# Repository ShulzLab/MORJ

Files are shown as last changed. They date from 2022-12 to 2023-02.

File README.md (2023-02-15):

## What does MORJ means anyway ?     

**MORJ** stands for **M**otorized **O**ptical **R**otary **J**oint, and is a device used for wide field fibroscopic imaging in freely moving animals.

It refers to a technical solution developed to enhance the use of dense multifibre beams for recording optical fluorescence signals in the brain of small, freely-moving animals. 

<div style="clear: both;">
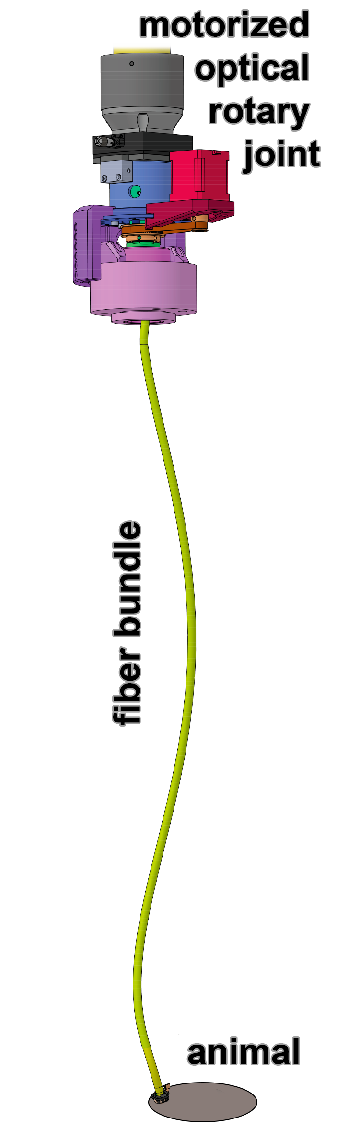
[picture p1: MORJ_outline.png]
MORJ
  
</div><h2> What is the rationale behind the development of this device ?</h2>

The use of rotating optical joints to allow light to pass through a fixed optical arrangement to one or a few rotating waveguides is quite common. However, there are few or no solutions for the use of dense multifibre waveguides. This usually leads neuroscientists wishing to study ethologically relevant behaviours in freely moving animals to use long sets of relatively rigid fibre bundles and to sporadically interrupt experiments to untangle the twist in the fibre as the animal moves and rotates, which in turn leads to disruption of the animal's behaviour.

The solution we have developed and described in this repository and in the peer-reviewed publication (*link Neurophotonics*) has allowed us to remove this limitation. By allowing rotation of the fibre bundle while being able to record stable sequences intermittently, it is possible to take full advantage of the use of fiberscopes to study natural behavioural repertoires.

## How does it works ?

In short, it uses an optical rotary joint similar to that described above, but adds motorised rotative control of angular position. This control is tuned to the orientation of the animal by directly reading its movements using an inertial measurement unit, and to the outputs of external devices so that it can be easily included in an experimental setup.

The rotation of the fiber bundle at the joint constantly follows the rotation of the animal while the controller is in "standby mode".

When fluorescence recording is desired, an electronic digital logic signal is used to trigger the controller into "recording mode". It instantly stops setting the rotation according to the animal's orientation and rather takes the shortest route to a precise and stable reference orientation. (OREF) It remains there while the recording is in progress. Once the recording is finished and the digital trigger signal goes low, the "standy mode" is used again.

More details on the operation of the device are available in the [`doc`](./doc) folder.

## What if I need to record over long periods of time without interruption ?

For the context in which we developed this device, we needed to make recordings of 1 second, approximately every 6 seconds depending on the animal's behaviour.

There are several solutions that can easily be implemented to make long recordings.

- In the case **short interruptions are acceptable**,  the simplest solution is to modify the behaviour of the joint controller so that the joint defaults to "record mode" and can control the start and stop of the acquisition device to which it is connected. When the torsion (the amount of rotation of the animal relative to the fixed position of the current 'record mode') exceeds a user-defined value, the 'record mode' is briefly stopped and so is the acquisition. The joint is rapidly rotated to the nearest reference orientation (OREF) where torsion is minimal. Once this movement is complete (full turns are completed in less than half a second with our device), the joint returns to the stable "recording mode" and commands the start of a new image sequence from the acquisition device. This process can continue indefinitely, resulting in image sequences of varying length depending on the rate of rotation of the animal.
- In the case **uninterrupted constant sampling rate signal is required**, a more complex solution is to rely of the fact that the motor position is known at all times. Thus, an alternate "constant recording mode" can be set, where the joint can move between periods of exposure of an image by the acquisition device.

At present, the first method has been implemented in the joint controller, but has not been tested in any significant experiments. The second method has not yet been implemented in the joint controller code, but will be developed in the future. 

## How can I build a device based on the same principle ?

- Build instructions are available here.

- 3D models documents and electronic parts and circuits are available in the [`electromechanical`](./electromechanical) folder.

- Code for the control and user interface are available in the [`software`](./software) folder.

## Why deciding to pattent this ?

The purpose of publishing and depositing this device was to make it available to other neuroscience researchers and to promote the study of ethologically relevant behaviours.

The publication and this current repository document the benefits, limitations, and future improvements associated with the device, and make this information available for others to use and replicate. However, adapting this device for your own laboratory will always represent a cost, including drawings and code, using or converting parts for your own particular optical system or fiber. Making or choosing your own electronics to control and interface with other parts of your installation can also be a substantial time investment. Although we have tried to make most of the information available to you so as not to go down the whole path of research and development that we did, you will still need a decent amount of man hours to build one and make it work reliably. Such time ressources in public research tend to be somewhat precious (scarce) ones, and the fact that an industrial company could take care of this for you in a more efficient and versatile way is also a great advantage for many labs. This is why we decided to patent this new design as it grants possible access to special funding from universities and technology transfer offices that may help cover the expenses of this knowledge transfer and associated product development for the industrial company.

If you are an industrial actor and would be interested in proposing to neurophysiological researchers a commercial product using the technology described in the [registered pattent](https://data.inpi.fr/brevets/FR3121999), you can contact us at isabelle.ferezou @t cnrs.fr or daniel.shulz @t cnrs.fr or timothe.jost-mousseau @t pasteur.fr

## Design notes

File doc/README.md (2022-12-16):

## Motorized Optical Rotary Joint :

#### - [Build Instructions](./build_instructions.md) 

#### - [Detailed explanation of elements and operating modes](./detailed_operations.md)

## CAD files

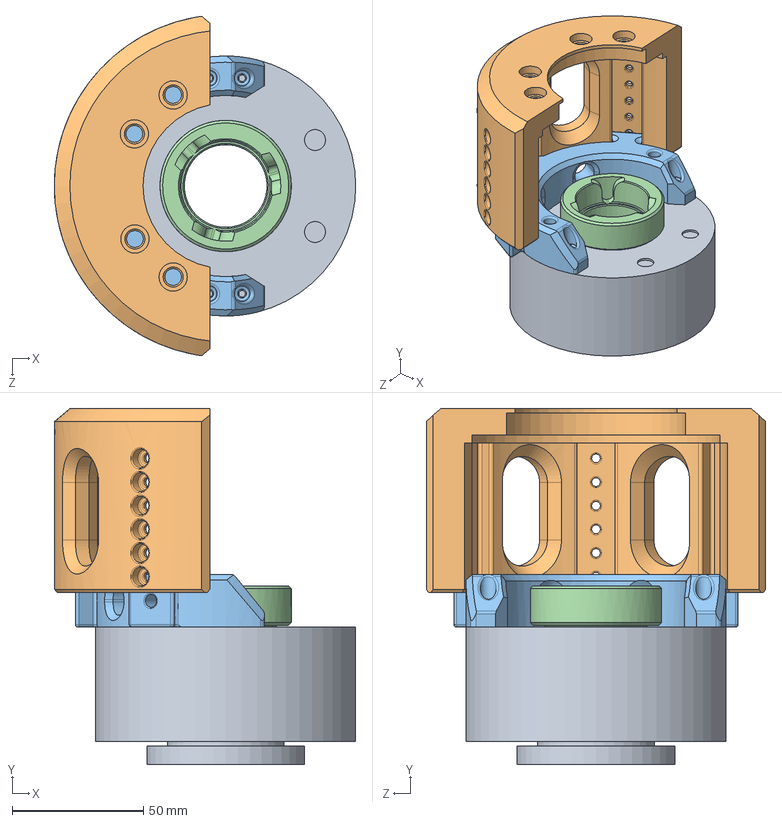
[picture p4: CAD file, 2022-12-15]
electromechanical/3D_files/electrical_rotary_joint/electrical_rotary_joint.SLDASM
114.7 x 135.5 x 129.2 mm
electrical_slip_ring_Jinpat_ LPT038-6
dovetail_fixed_body
dovetail_mobile_body
driving_ring

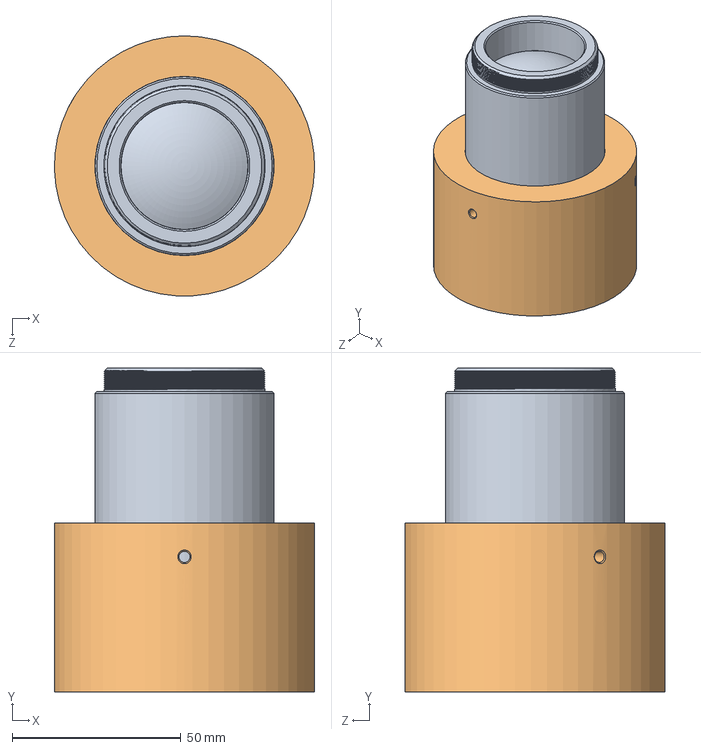
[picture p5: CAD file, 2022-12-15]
electromechanical/3D_files/upstream_optical_assembly/upstream_optical_assembly.SLDASM
77.1 x 96.0 x 77.1 mm
Lens
Lens_hood

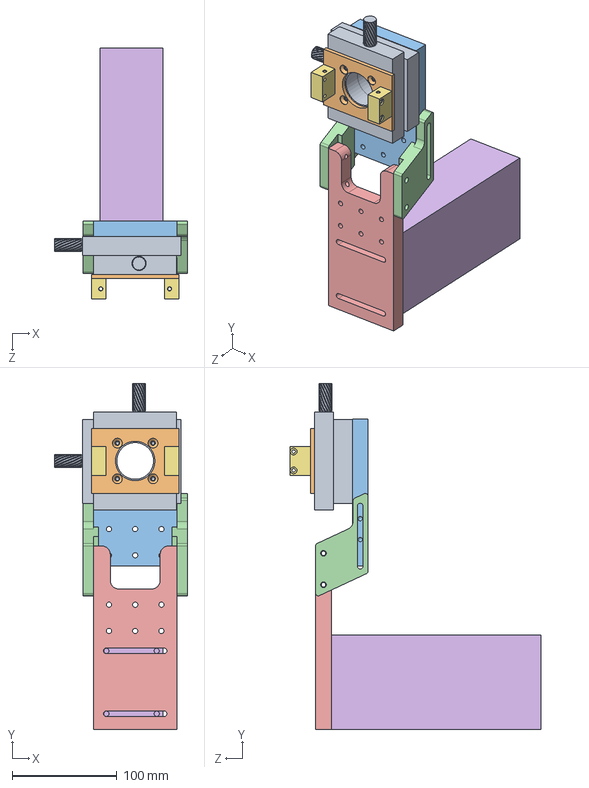
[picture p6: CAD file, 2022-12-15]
electromechanical/3D_files/xyz_adjustment_system/xyz_adjustment_system.SLDASM
127.1 x 330.0 x 239.5 mm
Platine_Ajustement
PlaqueInterne_LENS
Top_focus_holder
right_lateral_focus_holder x 2
Bottom_focus_holder
focus_adjuster_proxy
BlocAdaptation x 2

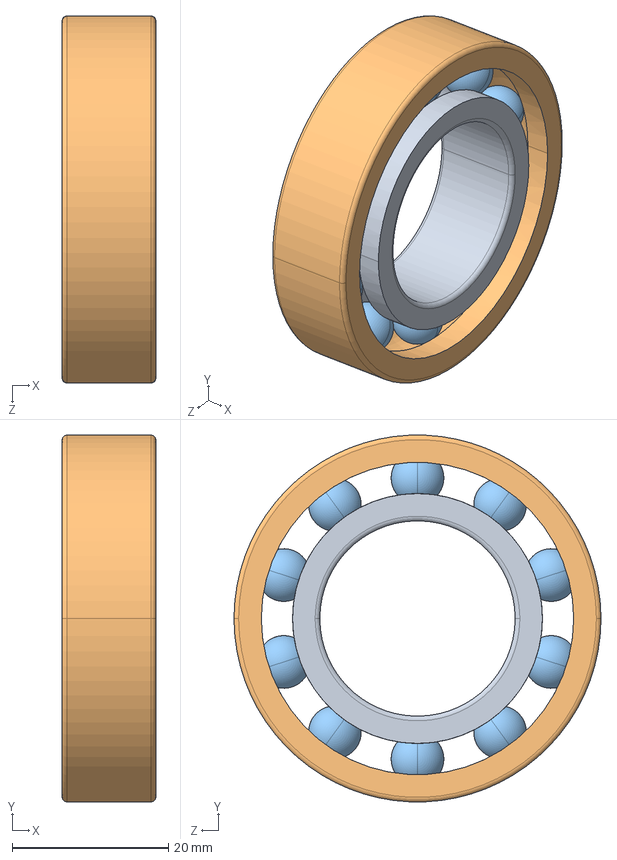
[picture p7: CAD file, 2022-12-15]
electromechanical/3D_files/optical_rotary_joint/roller_bearing/RollerBearing_6005_HC5C3.SLDASM
12.0 x 47.0 x 47.0 mm
inner_grove
outer_grove
roller_ball x 10

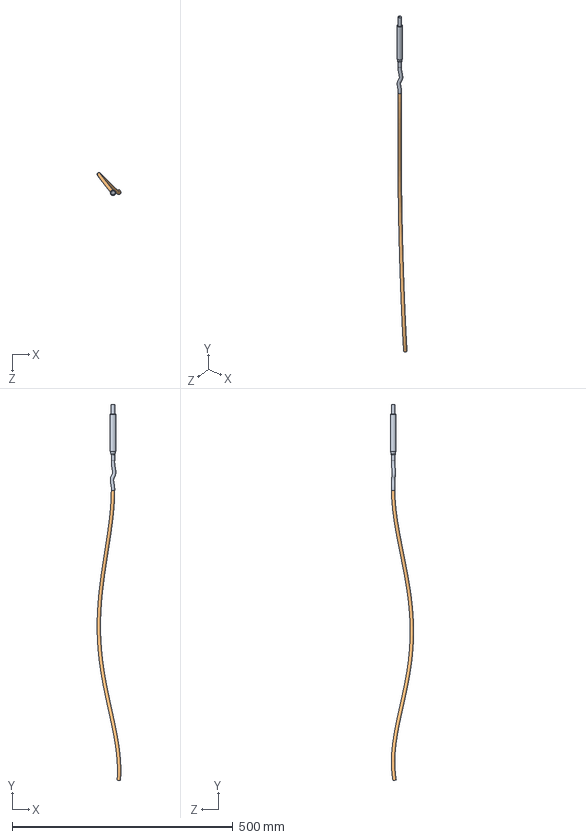
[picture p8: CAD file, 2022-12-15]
electromechanical/3D_files/downstream_optical_assembly/downstream_optical_assembly.SLDASM
53.9 x 851.9 x 52.6 mm
Fiber_proximal_end
Fiber_body

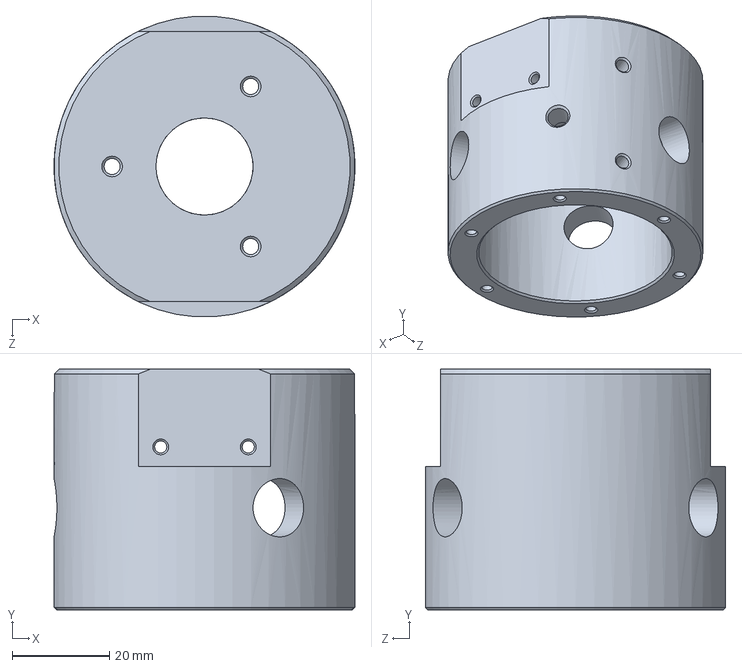
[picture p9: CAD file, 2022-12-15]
electromechanical/3D_files/optical_rotary_joint/main_static_body.SLDPRT
61.9 x 49.5 x 61.8 mm

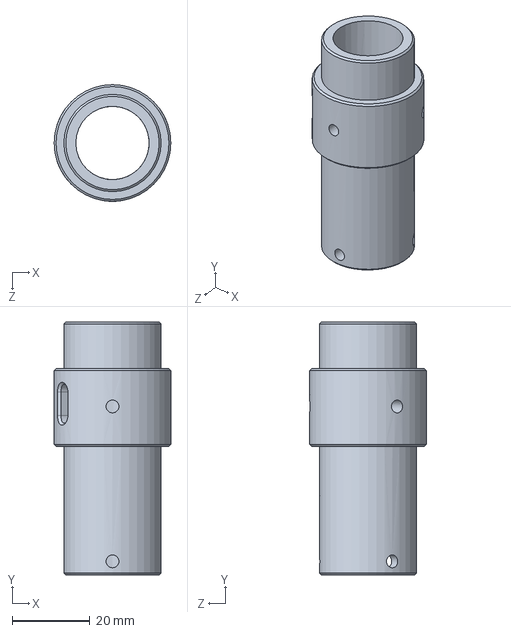
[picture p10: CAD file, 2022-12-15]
electromechanical/3D_files/optical_rotary_joint/main_rotative_body.SLDPRT
30.0 x 65.0 x 30.0 mm

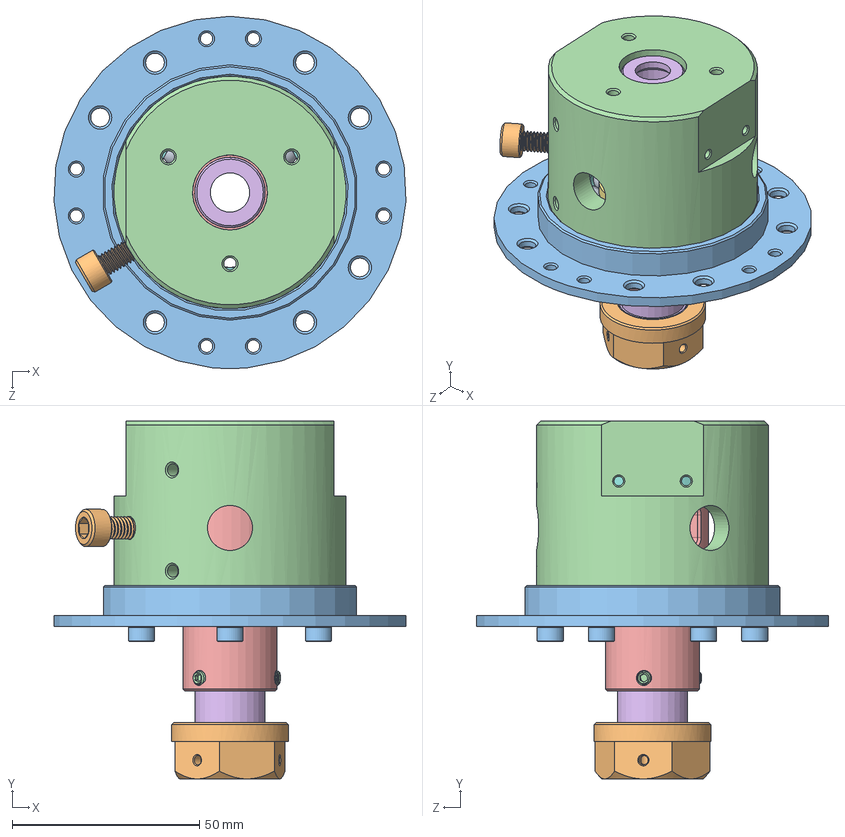
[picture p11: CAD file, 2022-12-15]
electromechanical/3D_files/optical_rotary_joint/optical_rotary_joint.SLDASM
93.9 x 95.4 x 94.0 mm
spacer
tightening_nut
endplate
main_static_body
main_rotative_body
adjustable_height_rotative_body
inner_grove x 2
outer_grove x 2
roller_ball x 20
lock_tightening_pin
BTR_M6 x 6
setscrew_M4 x 6

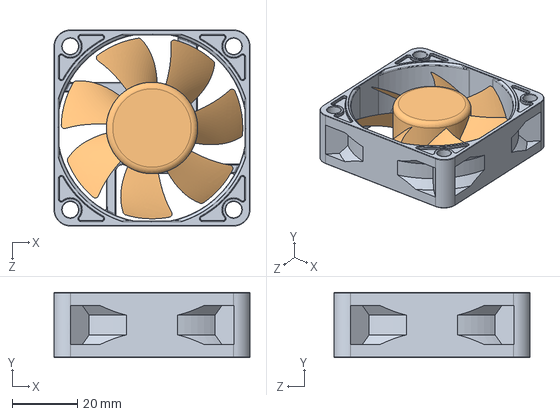
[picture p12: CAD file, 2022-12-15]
electromechanical/3D_files/motor_controller/60mm_fan.SLDASM
60.0 x 20.0 x 60.0 mm
Fan_Case
Fan

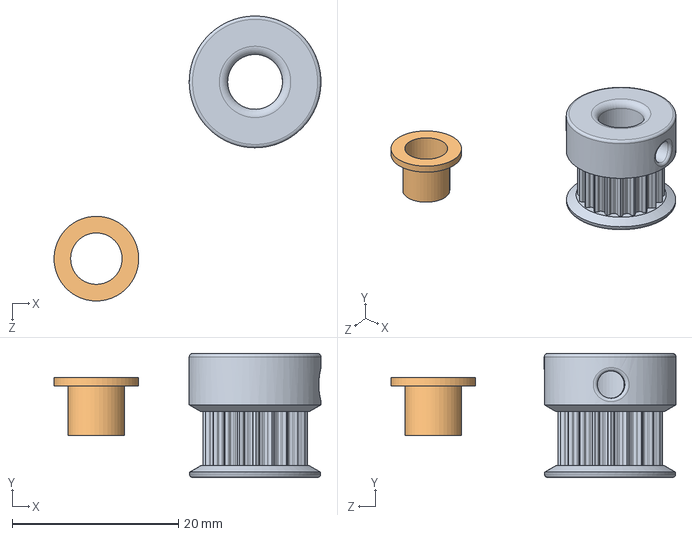
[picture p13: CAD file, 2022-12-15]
electromechanical/3D_files/motor_system/motor_system.SLDASM
32.1 x 14.9 x 34.3 mm
Pulley_GT2_20T
Plot_Roulementplastique

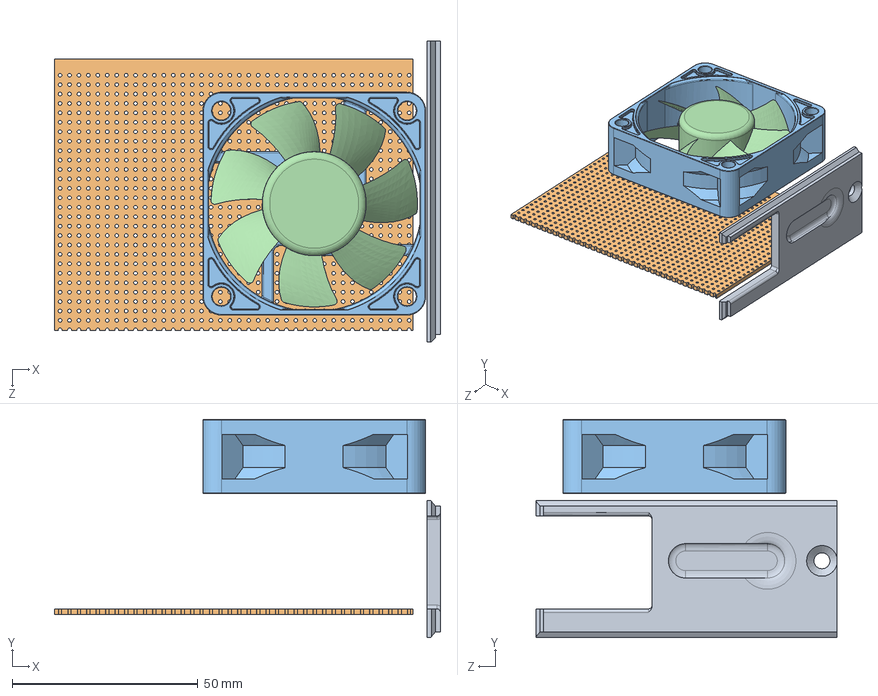
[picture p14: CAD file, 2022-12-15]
electromechanical/3D_files/motor_controller/motor_controller.SLDASM
103.9 x 58.7 x 80.9 mm
proto_board
Fan_Case
Fan
driver_opening_plate

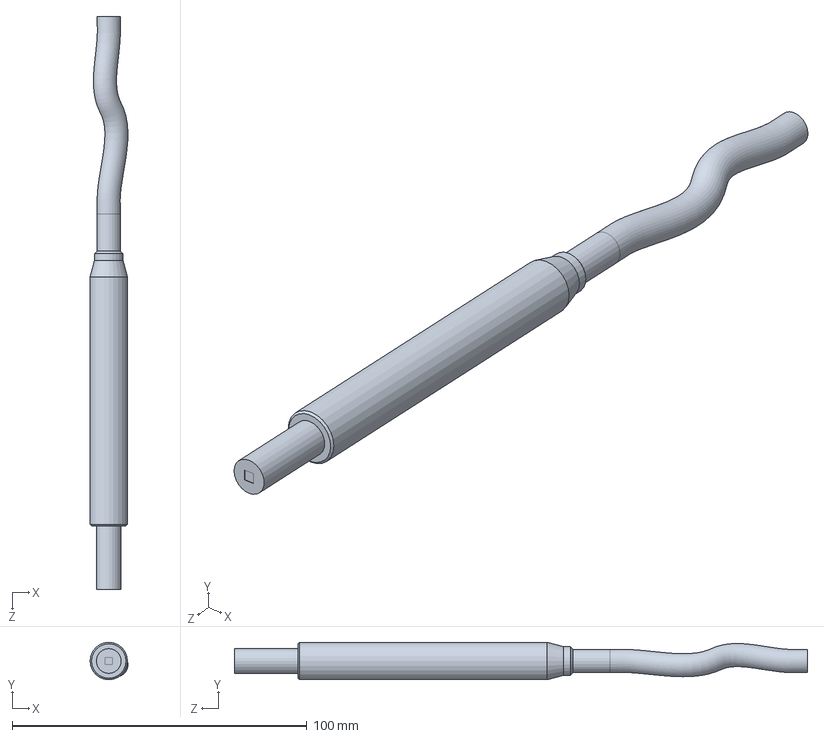
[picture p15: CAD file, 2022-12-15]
electromechanical/3D_files/downstream_optical_assembly/Fiber_proximal_end.SLDPRT
12.9 x 12.7 x 194.3 mm

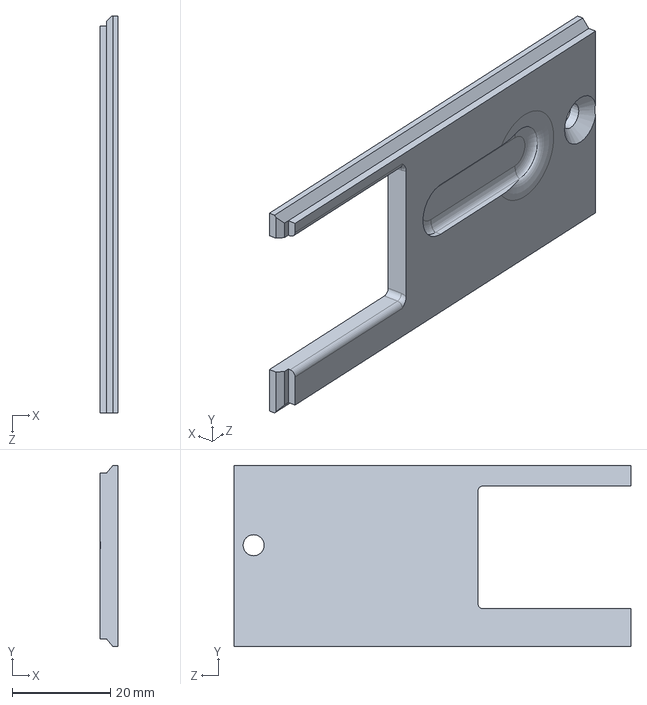
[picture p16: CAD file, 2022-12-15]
electromechanical/3D_files/motor_controller/driver_opening_plate.SLDPRT
3.70 x 36.9 x 80.9 mm

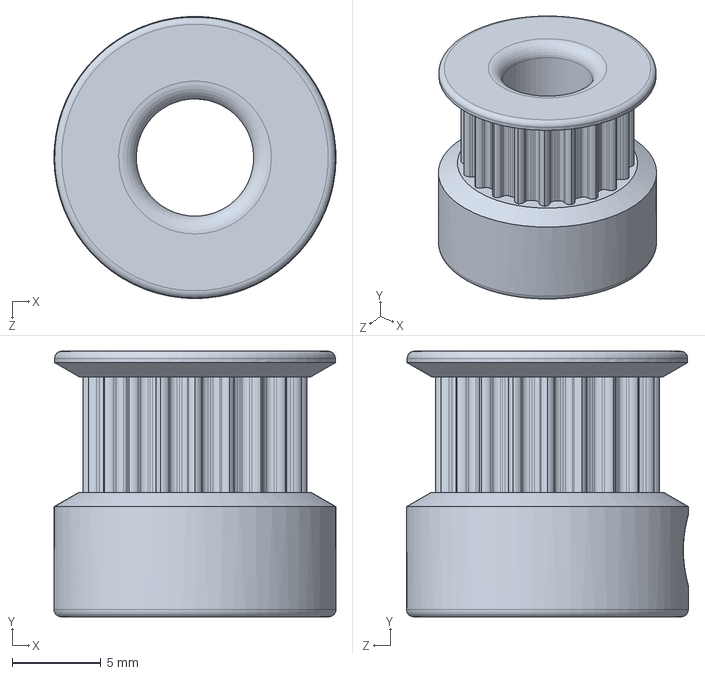
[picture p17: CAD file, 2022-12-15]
electromechanical/3D_files/motor_system/Pulley_GT2_20T.SLDPRT
15.9 x 14.9 x 15.9 mm

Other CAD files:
electromechanical/3D_files/optical_rotary_joint/roller_bearing/outer_grove.SLDPRT
electromechanical/3D_files/downstream_optical_assembly/Fiber_body.SLDPRT
electromechanical/3D_files/electrical_rotary_joint/dovetail_fixed_body.SLDPRT
electromechanical/3D_files/motor_controller/proto_board.SLDPRT
electromechanical/3D_files/electrical_rotary_joint/dovetail_mobile_body.SLDPRT
electromechanical/3D_files/electrical_rotary_joint/driving_ring.SLDPRT
electromechanical/3D_files/electrical_rotary_joint/electrical_slip_ring_Jinpat_ LPT038-6.SLDPRT
electromechanical/3D_files/motor_controller/Fan.SLDPRT
electromechanical/3D_files/motor_controller/Fan_Case.SLDPRT
electromechanical/3D_files/motor_controller/USB_port.SLDPRT
electromechanical/3D_files/motor_controller/attachment_plate.SLDPRT
electromechanical/3D_files/motor_controller/connectors_opening_plate.SLDPRT
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

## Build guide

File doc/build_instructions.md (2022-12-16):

## Build Instructions :

There instructions are to reproduce the device with the files provided in this repository. However, it will be highly likely that you will need to make changes to the design to adapt for your particular situation (optical measurement setup available, dimenstions of the fiber bundle available)

### 1 - The fiber bundle :

The fiber bundle we used is designed by Schott, and is a large diameter (6.25 mm²) [wound image bundle](https://www.schott.com/en-ro/products/flexible-imaging-bundles-p1000343/product-variants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).

<div class="column">
  <div class="row">
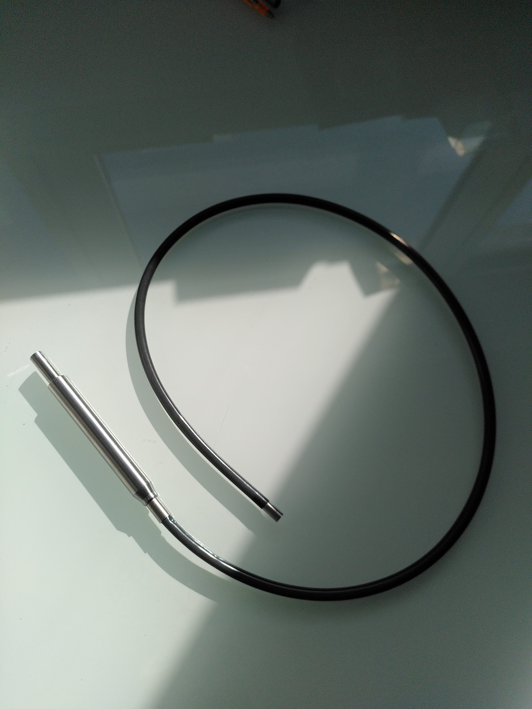
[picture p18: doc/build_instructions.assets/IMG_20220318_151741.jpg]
    
  </div>
  <div class="row">
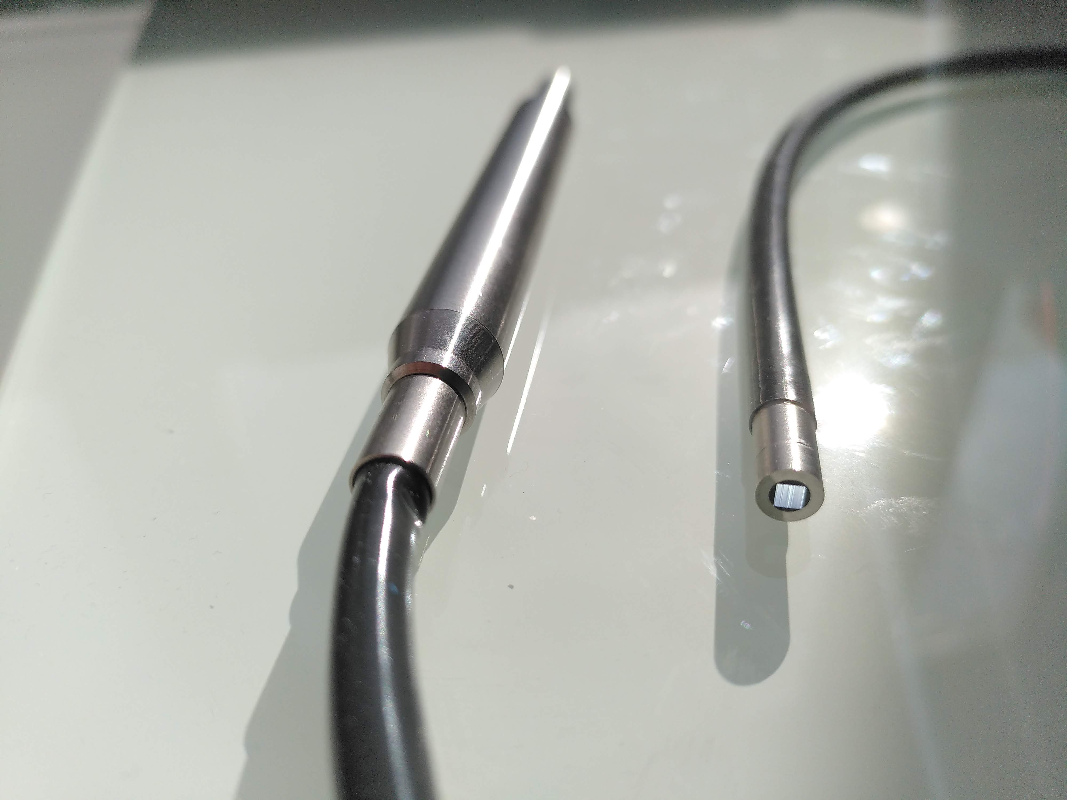
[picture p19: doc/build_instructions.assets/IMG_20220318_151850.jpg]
    
  </div>
</div> 

### 2 - Adapting dimensions to the fiber and objective
<div class="column">
  <div class="row">
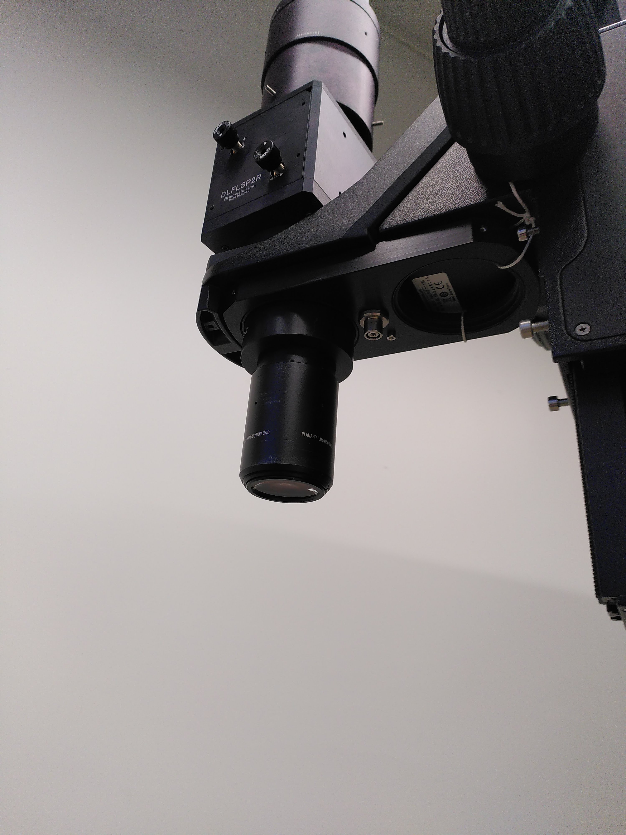
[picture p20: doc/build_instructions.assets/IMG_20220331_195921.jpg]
    
  </div>
  <div class="row">
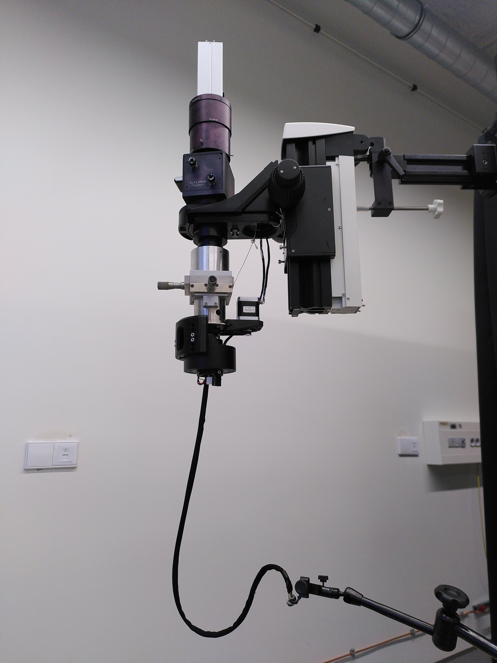
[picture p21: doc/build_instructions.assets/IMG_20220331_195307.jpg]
    
  </div>
</div>

#### From simple "fiber below lens" static mount

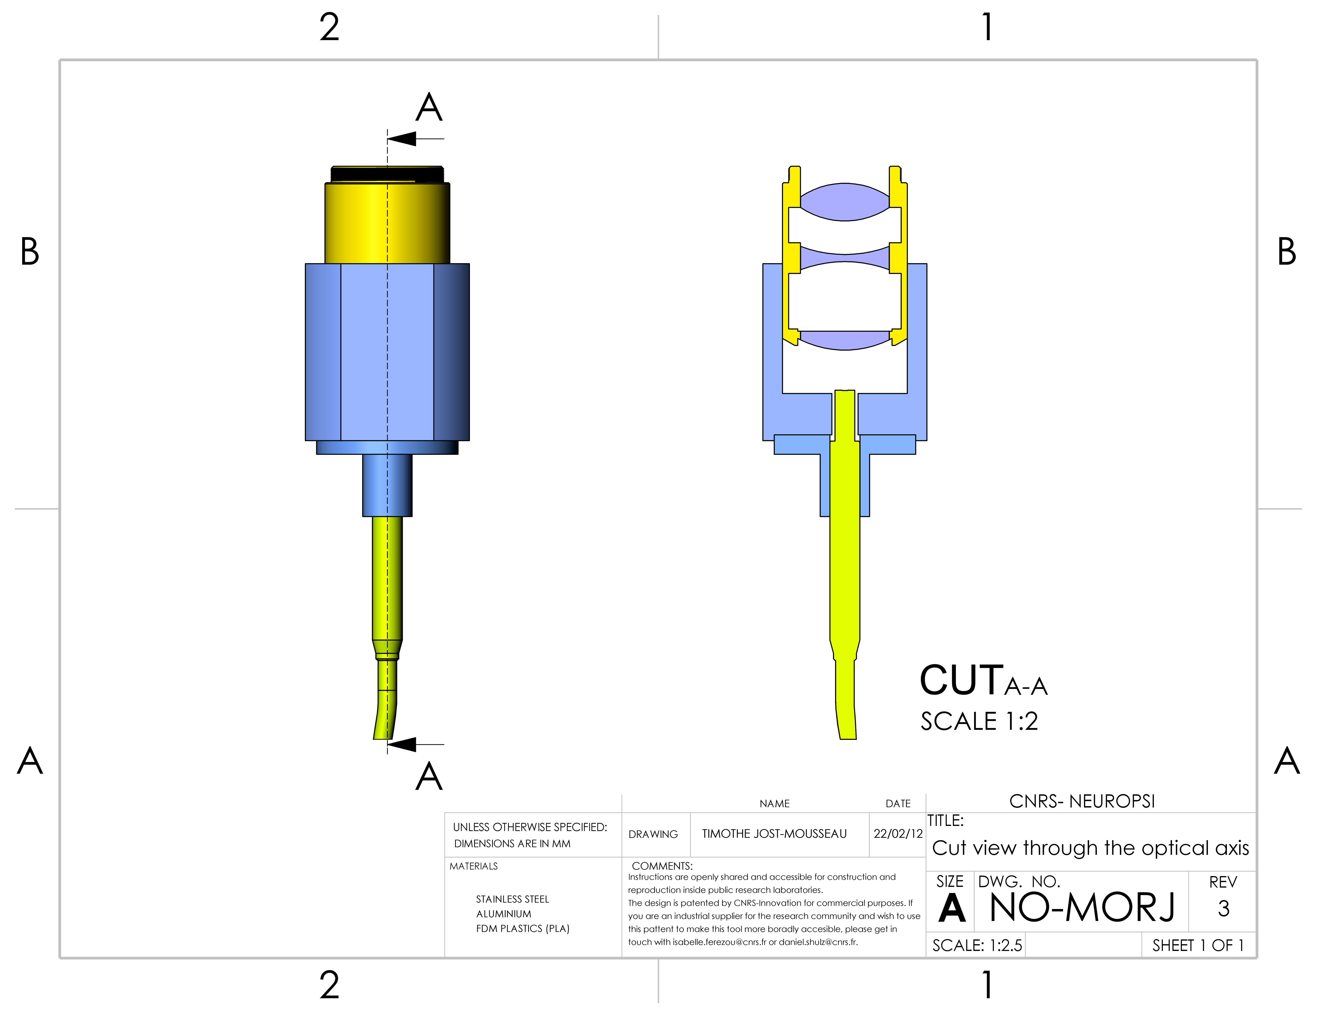
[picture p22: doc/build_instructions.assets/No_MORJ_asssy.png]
No_MORJ_asssy


#### To rotative joint with adapted dimensions for fiber, motor, bearings & electrical joint

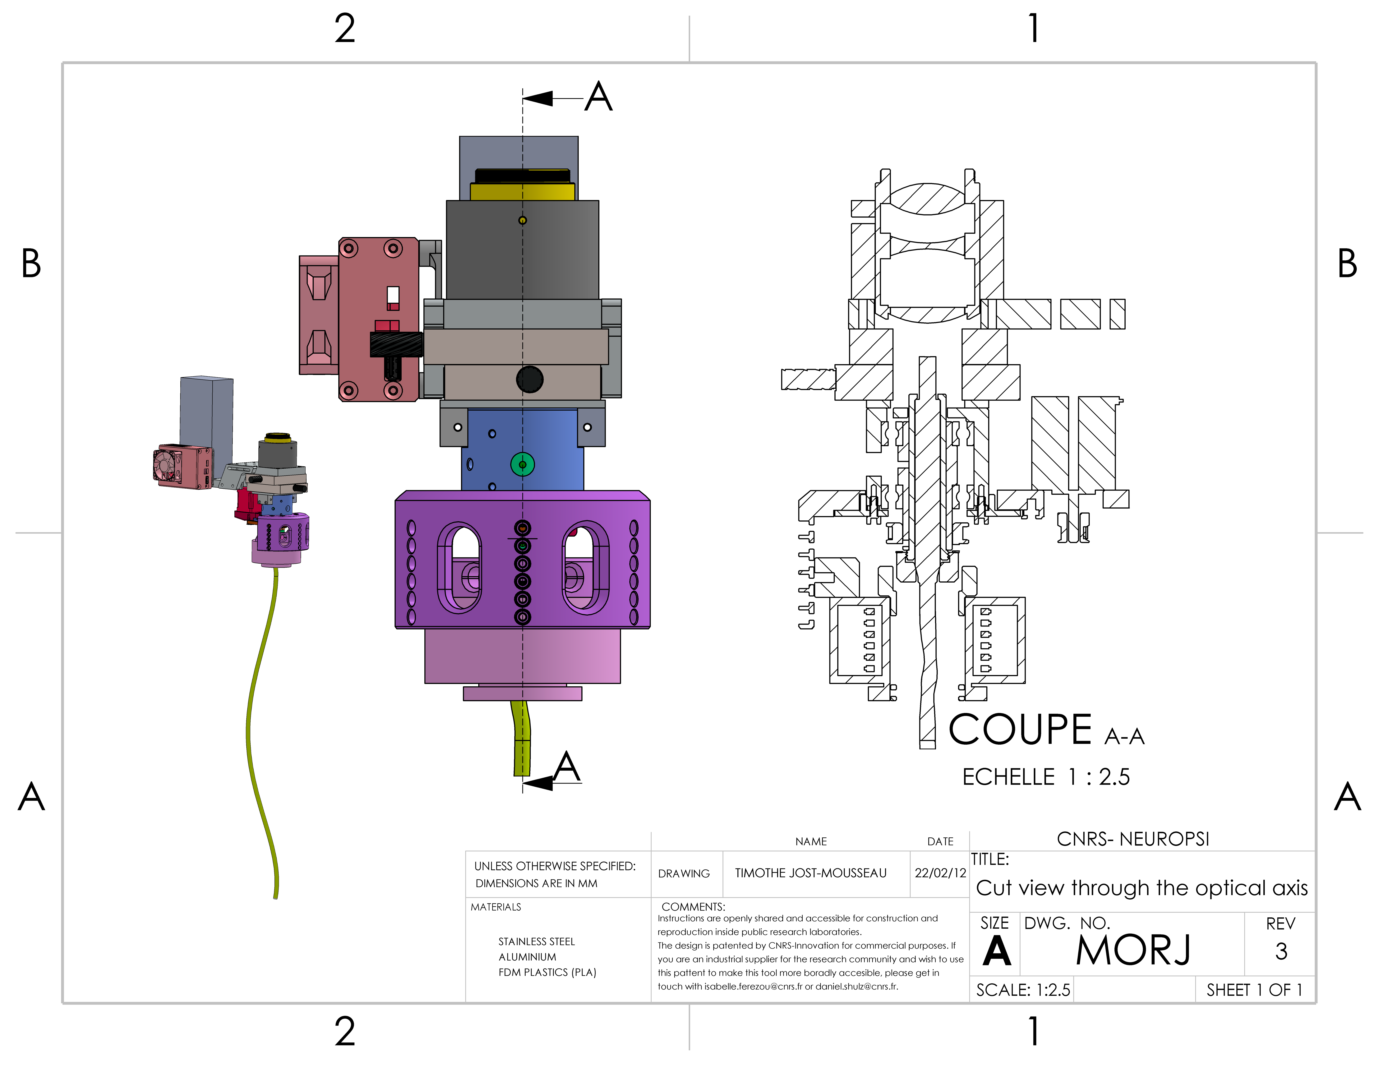
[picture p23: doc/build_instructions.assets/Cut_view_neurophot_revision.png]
Cut_view_neurophot_revision


Planning ahead for a system to adjust focus (Z) and lateral shift (X, Y) with a 2d translation platform is quite handy and important.

### 3 - The inertial measurement unit board

<div class="column">
  <div class="row">
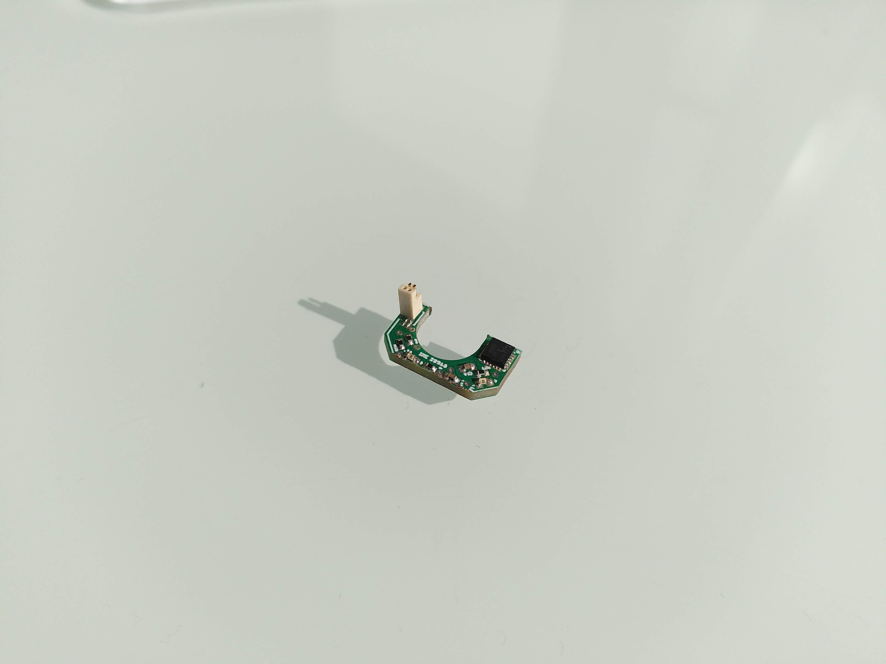
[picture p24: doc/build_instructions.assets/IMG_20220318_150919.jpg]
    
  </div>
  <div class="row">
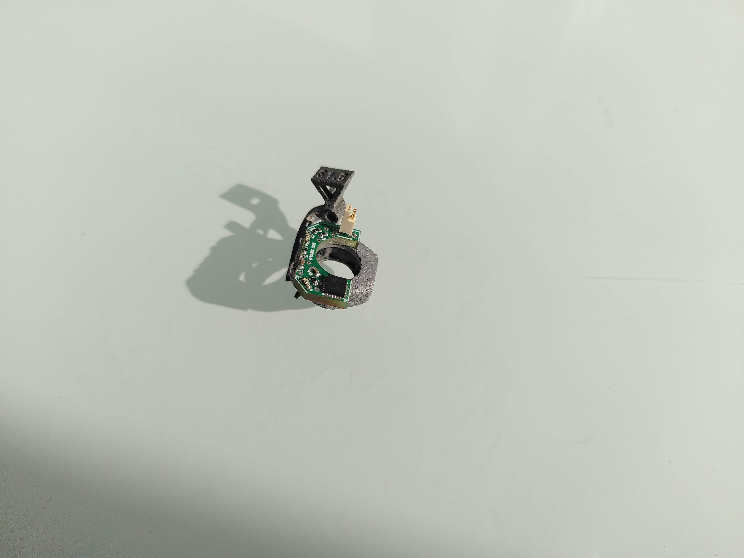
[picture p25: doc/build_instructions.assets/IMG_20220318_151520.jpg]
    
  </div>
</div>

### 4 - Electronic control

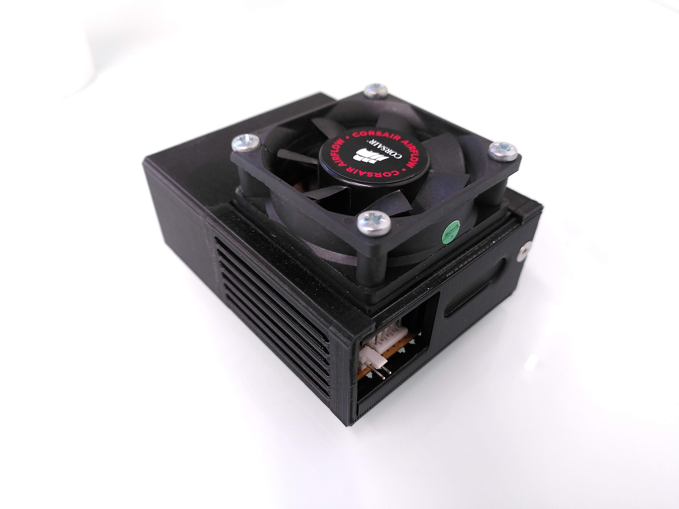
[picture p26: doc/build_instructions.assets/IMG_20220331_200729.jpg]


## 5 - User interface

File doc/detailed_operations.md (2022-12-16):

## All modes of operations :

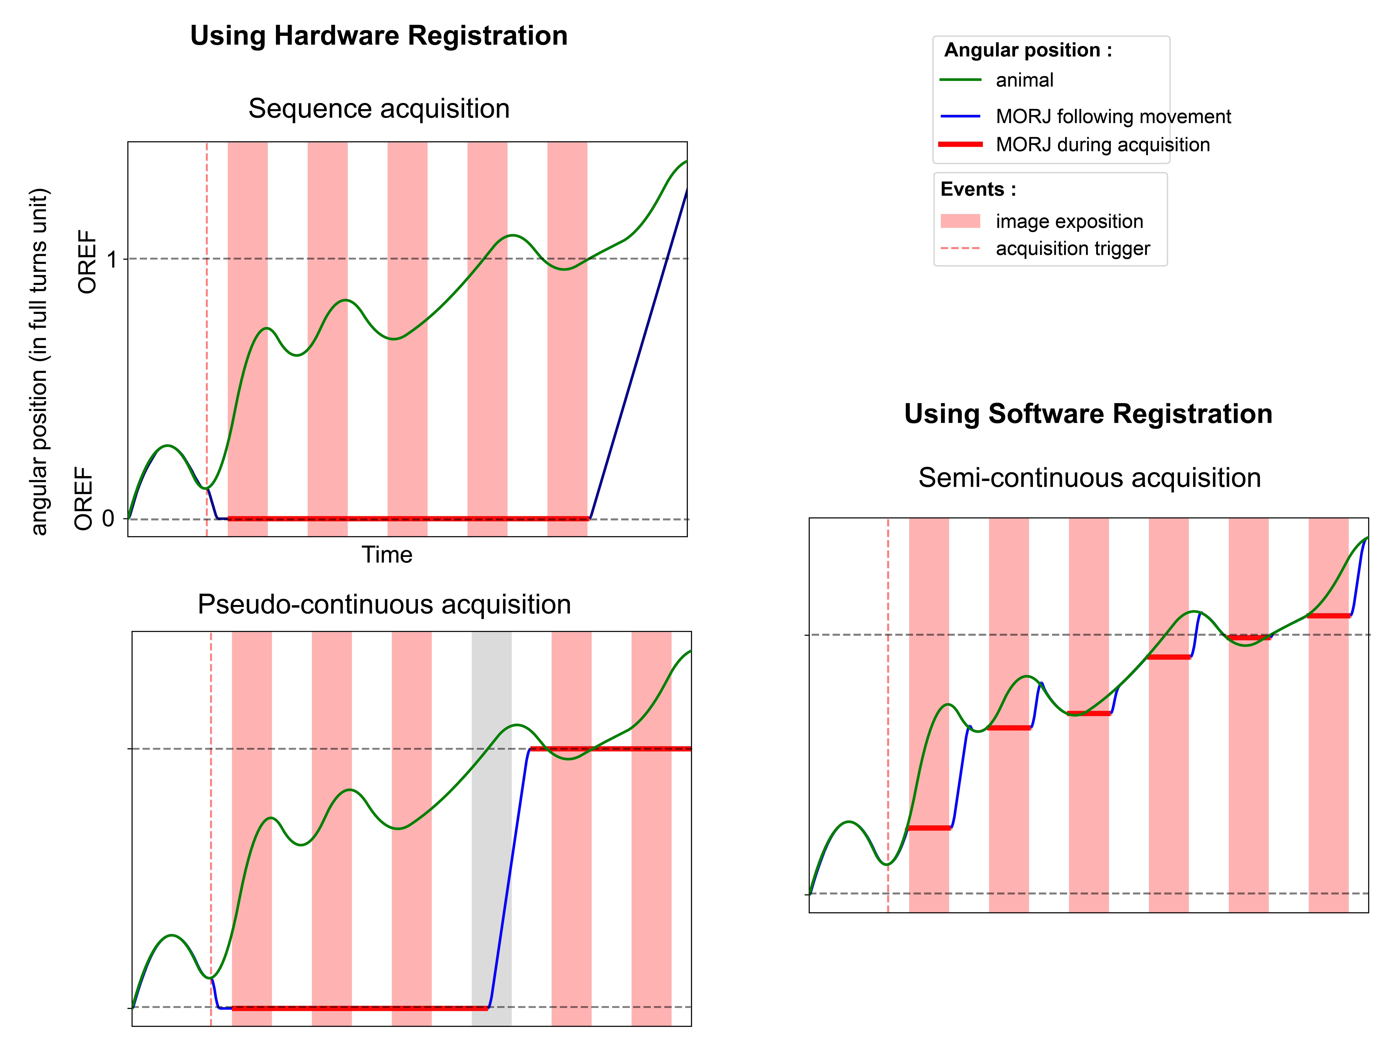
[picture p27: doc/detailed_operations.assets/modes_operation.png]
modes_operation


### Automation process :

[Controller flowchart](detailed_operations.assets/MORJ_controller.pdf)

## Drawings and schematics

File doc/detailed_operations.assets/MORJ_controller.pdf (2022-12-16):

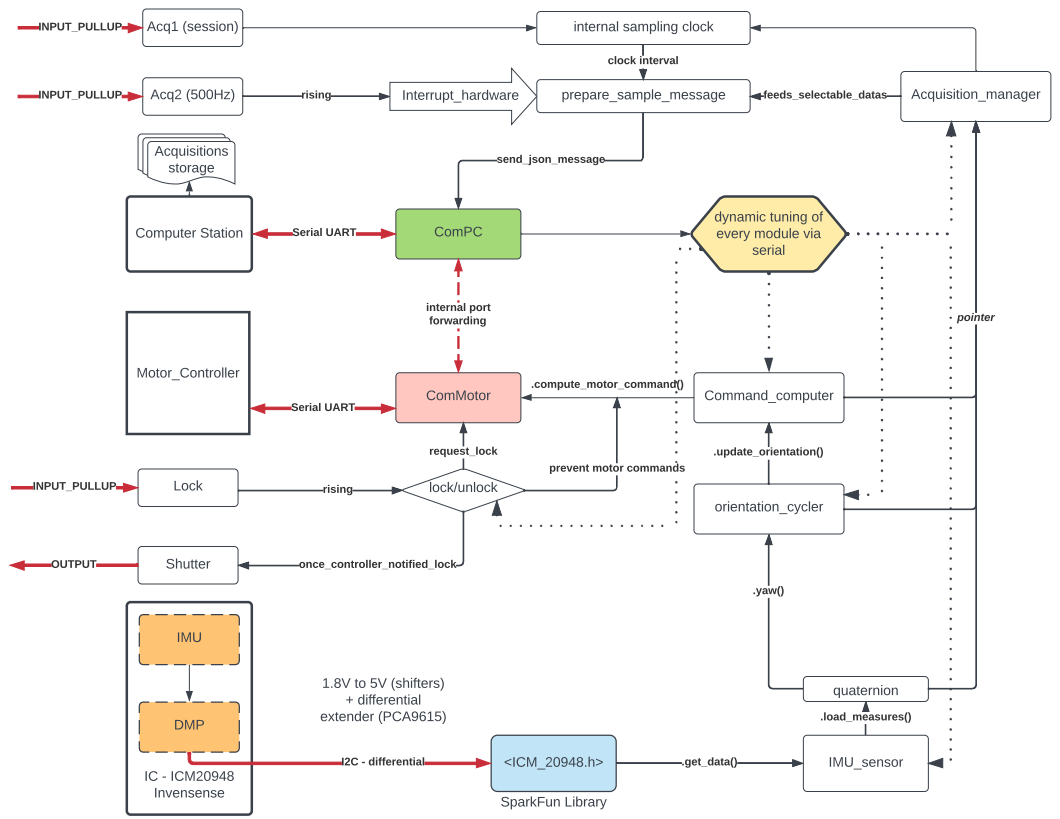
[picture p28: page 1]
IMU; DMP; <ICM_20948.h>; SparkFun Library; I2C - differential; IC - ICM20948 Invensense; 1.8V to 5V (shifters) + differential extender (PCA9615); .get_data(); IMU_sensor; .load_measures(); quaternion; pointer; Acquisition_manager; .yaw(); orientation_cycler; .update_orientation(); ComMotor; Command_computer; .compute_motor_command(); Motor_Controller; Serial UART; Computer Station; ComPC; internal port forwarding; Lock; Shutter; Acq1 (session); INPUT_PULLUP; OUTPUT; Acq2 (500Hz)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

internal sampling clock

dynamic tuning of
every module via
serial

prevent motor commands

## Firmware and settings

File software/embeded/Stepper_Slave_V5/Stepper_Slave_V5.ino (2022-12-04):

#include <stdint.h>

#define PROTOCOL_NO_WAIT_JSON_AKNOWLEDGE 1
#define ARDUINOJSON_DECODE_UNICODE 1
#define PROTOCOL_ITEM_NUMBER 6
#define PROTOCOL_DEBUG_MODE 0


#include "ArduPPPJS.h"
//#include <avr/wdt.h>

#include "DriverClass.h"

#define INTERNAL_TMC_UART Serial5  // UART serial port used to communicate with TMC driver
#define EXTERNAL_DATA_UART Serial4
#define EXTERNAL_COMPUTER_UART Serial

#define INITIALIZATION_WAIT_PERIOD 6000

const int Pin_GreenLED = 12;
const int Pin_RedLED = 11;

constexpr auto glb_Pin_MotorEnable = 7;
constexpr auto glb_Pin_MS1 = 5;
constexpr auto glb_Pin_MS2 = 6;

constexpr auto glb_Pin_Step = 3;
constexpr auto glb_Pin_Dir = 2;

constexpr auto DRIVER_ADDRESS = 0b00;

constexpr float R_SENSE = 0.11;
//#define R_SENSE 0.11f // Match to your driver

int RDOfreq = 100;
bool RDOflag = false;

IntervalTimer RDO_timer;

MORJStepperDriver StepMotor(INTERNAL_TMC_UART, R_SENSE, DRIVER_ADDRESS, glb_Pin_Step, glb_Pin_Dir, glb_Pin_MS1, glb_Pin_MS2);

BJ_ProtocolHandler<PROTOCOL_ITEM_NUMBER> IOs;



#define com_type int32_t
#define com_id 10
#define mpos_type int32_t
#define mpos_id 20
#define abscom_type int32_t
#define abscom_id 30
//#define virtual_type float
//#define virtual_id 230
//#define virtual_type_2 uint64_t
//#define virtual_id_2 158

void PayloadSetup() {
	IOs.append<com_type>(com_id, "command");
	IOs.append<mpos_type>(mpos_id, "motor_pos");
	IOs.append<abscom_type>(abscom_id, "abs_motor_command");
	//IOs.append<virtual_type>(virtual_id, "virtual_float");
	//IOs.append<virtual_type_2>(virtual_id_2, "virtual_uint64");
}

void setup() {
	PayloadSetup();

	pinMode(LED_BUILTIN, OUTPUT);
	pinMode(Pin_GreenLED, OUTPUT);
	pinMode(Pin_RedLED, OUTPUT);
	digitalWrite(LED_BUILTIN, LOW);

	static bool COMPUTER_CONNECTED = false;
	EXTERNAL_COMPUTER_UART.begin(250000);
	while (millis() < INITIALIZATION_WAIT_PERIOD) {
		Wait_and_BlinkLEDs();
		if (EXTERNAL_COMPUTER_UART) {
			COMPUTER_CONNECTED = true;
			break;
		}
	}

	// put your setup code here, to run once:
	INTERNAL_TMC_UART.begin(115200);

	if (COMPUTER_CONNECTED) {
		IOs.begin(EXTERNAL_COMPUTER_UART, EXTERNAL_COMPUTER_UART);
		StepMotor.begin(3, 400, 8, glb_Pin_MotorEnable, EXTERNAL_COMPUTER_UART);
		StepMotor.connectLED(Pin_RedLED);
		StepMotor.SetLedMode(true);
		digitalWrite(Pin_GreenLED, LOW);
		EXTERNAL_COMPUTER_UART.println("{started_in_mode:'computer_usb'}");
	}
	else {
		EXTERNAL_DATA_UART.begin(115200);
		delay(250);
		IOs.begin(EXTERNAL_DATA_UART, EXTERNAL_COMPUTER_UART);
		StepMotor.begin(3, 400, 8, glb_Pin_MotorEnable, EXTERNAL_DATA_UART);
		StepMotor.connectLED(Pin_GreenLED);
		StepMotor.SetLedMode(false);
		digitalWrite(Pin_RedLED, LOW);
		EXTERNAL_COMPUTER_UART.println("{started_in_mode:'external_device'}");
	}

	RDO_timer.priority(129);
	RDO_timer.begin(RDO_IRQ, (long)(1000000 / RDOfreq));

	//StepMotor.toff(5);

	StepMotor.SetMotorCurrent(1600);

	StepMotor.AccelStepper::setMaxSpeed(10000);
	StepMotor.SetMotorAcceleration(20000);
	EXTERNAL_COMPUTER_UART.println("{setup_init:'finished'}");
};

void loop() {
	MessageHandlers();

	bool _temp_lock = StepMotor.EvaluateMovement();
  if (_temp_lock){
    IOs.AddKeyValue_JSON("locked", true);
    IOs.Send_JSON();
  }
	AltLEDS_builtin();
};

void MessageHandlers() {

	IOs.CommsHandler();
	if (IOs.jsonAvailable) {
		JsonInterpreter();
	}
	if (IOs[mpos_id].available == 1) {
		char result[16];
		IOs[mpos_id].getValue<mpos_type>();
		dtostrf(StepMotor.currentPosition(), 12, 0, result);
		IOs.AddKeyValue_JSON("motor_current_pos", result);
		IOs.Send_JSON();
	}
	if (IOs[com_id].available == 1) {
		/*char result[16];
		dtostrf(IOs[com_id].getValue<com_type>(), 12, 0, result);
		IOs.AddKeyValue_JSON("motor_command_recieved", result);
		IOs.Send_JSON();*/
		StepMotor.NewCommand(IOs[com_id].getValue<com_type>());
	}
	if (IOs[abscom_id].available == 1) {
	  bool statux = StepMotor.AbsCommand(IOs[com_id].getValue<com_type>());
    if (statux){
      IOs.AddKeyValue_JSON("abs_exec",true);
      IOs.Send_JSON();
    }
    else {
      IOs.AddKeyValue_JSON("abs_exec",false);
      IOs.Send_JSON();
    }
	}

	//if (IOs[virtual_id].available == 1) {
	//	char result[16];
	//	dtostrf(IOs[virtual_id].getValue<virtual_type>(), 12 , 5 ,result);
	//	IOs.AddKeyValue_JSON("printed_var_float", result);
	//	IOs.Send_JSON();
	//}
	//if (IOs[virtual_id_2].available == 1) {
	//	char result[16];
	//	dtostrf(IOs[virtual_id_2].getValue<virtual_type_2>(), 12, 0, result);
	//	IOs.AddKeyValue_JSON("printed_var_int64", result);
	//	IOs.Send_JSON();
	//}
};


void RDO_IRQ() {
	if (StepMotor._RDOfreq != RDOfreq) {
		RDO_timer.update((long)(1000000 / RDOfreq));
		RDOfreq = StepMotor._RDOfreq;
	}
	if (StepMotor._RDO_status == true) {
		RDOflag = true;
	}
};

void RDO_main_handler(){
	if (RDOflag){
		mpos_type data = StepMotor.currentPosition();
		IOs[mpos_id].setValue(data);
		IOs.SendHex(mpos_id);
		RDOflag = false;
	}
}

void Wait_and_BlinkLEDs() {
	static unsigned long _memo = 0;
	static bool _status = 0;
	static unsigned int _delay = 100;
	if (_delay == 100 && millis() > INITIALIZATION_WAIT_PERIOD - (INITIALIZATION_WAIT_PERIOD/4)) {
		_delay = 50;
	}
	if (millis() - _memo > _delay) {
		digitalWrite(Pin_GreenLED, _status);
		digitalWrite(Pin_RedLED, _status);
		_status = !_status;
		_memo = millis();
	}
};

void AltLEDS_builtin() {
	static bool led = 0;
	static unsigned long lasttime = 0;
	if (StepMotor._led_active) {
		if (millis() - lasttime > 50) {
			lasttime = millis();
			if (led == 0) {
				led = 1;
				digitalWrite(LED_BUILTIN, LOW);
			}
			else {
				led = 0;
				digitalWrite(LED_BUILTIN, HIGH);
			}
		}
	}
};

void JsonInterpreter() {
	bool ValidKey = 0;

	if (PROTOCOL_DEBUG_MODE){
		IOs._DirectSendInput();
	}	

	if (IOs.jsonInput.containsKey("set_led_mode")) {
		StepMotor.SetLedMode((bool)IOs.jsonInput["led_mode"]);
		ValidKey = 1;
	}

	if (IOs.jsonInput.containsKey("handshake")){
		IOs.AddKeyValue_JSON("accept_handshake", "1");
		IOs.Send_JSON();
		ValidKey = 1;
	}

	if (IOs.jsonInput.containsKey("enb_rdout")) {
		if ((bool)IOs.jsonInput["enb_rdout"] == 0) {
			StepMotor.StopRDO();
		}
		else {
			StepMotor.StartRDO((long)IOs.jsonInput["enb_rdout"]);
		}
		ValidKey = 1;
	}

	if (IOs.jsonInput.containsKey("get_pos")) {
		mpos_type data = StepMotor.currentPosition();
		char result[16];
		dtostrf(data, 12, 0, result);
		IOs.AddKeyValue_JSON("current_position", result);
		IOs.Send_JSON();
		ValidKey = 1;
	}

	if (IOs.jsonInput.containsKey("set_motor_scale")) {
		StepMotor.SetMotorPrecision((uint16_t)IOs.jsonInput["set_motor_scale"]);
		ValidKey = 1;
	}

	if (IOs.jsonInput.containsKey("get_inc_per_rev")) {
		char temp[16] = "";
		StepMotor.GetMotorScale(temp);
		IOs.AddKeyValue_JSON("inc_per_rev", temp);
		IOs.Send_JSON();
		ValidKey = 1;
	}

	if (IOs.jsonInput.containsKey("set_motor_max_speed")) {
		StepMotor.setMaxSpeed((long)IOs.jsonInput["set_motor_max_speed"]);
		ValidKey = 1;
	}

	if (IOs.jsonInput.containsKey("set_motor_accel")) {
		StepMotor.SetMotorAcceleration((long)IOs.jsonInput["set_motor_accel"]);
		ValidKey = 1;
	}

	if (IOs.jsonInput.containsKey("set_motor_enable")) {
		StepMotor.SetMotorEnable((bool)IOs.jsonInput["set_motor_enable"]);
		ValidKey = 1;
	}

	if (IOs.jsonInput.containsKey("set_motor_spread_mode")) {
		StepMotor.en_spreadCycle((bool)IOs.jsonInput["set_motor_spread_mode"]);
		ValidKey = 1;
	}

	if (IOs.jsonInput.containsKey("set_motor_current")) {
		StepMotor.SetMotorCurrent((long)IOs.jsonInput["set_motor_current"]);
		ValidKey = 1;
	}

	if (IOs.jsonInput.containsKey("go")) {
		StepMotor.NewCommand((long)IOs.jsonInput["go"]);
		ValidKey = 1;
	}

  if (IOs.jsonInput.containsKey("go_abs")) {
    bool statux = StepMotor.AbsCommand((long)IOs.jsonInput["go_abs"]);
    if (statux){
      IOs.AddKeyValue_JSON("abs_exec",true);
      IOs.Send_JSON();
    }
    else {
      IOs.AddKeyValue_JSON("abs_exec",false);
      IOs.Send_JSON();
    }
    ValidKey = 1;
  } 

	if (IOs.jsonInput.containsKey("zero")) {
		StepMotor.SetZero();
		ValidKey = 1;
	}

	if (IOs.jsonInput.containsKey("stop")) {
		StepMotor.StopMotor();
		ValidKey = 1;
	}

	if (IOs.jsonInput.containsKey("lock")) {
		if ((bool)IOs.jsonInput["lock"] == false) {
			StepMotor.Unlock();
      IOs.AddKeyValue_JSON("locked",false);
      IOs.Send_JSON();
		}
		else if ((bool)IOs.jsonInput["lock"] == true) {
			StepMotor.LockToNearestZero();
		}
		ValidKey = 1;
	}

  if (IOs.jsonInput.containsKey("get_turn_count")) {
   long temp_turns = StepMotor.Turns_Calc();
   IOs.AddKeyValue_JSON("turn_count", temp_turns);
   IOs.Send_JSON();
   ValidKey = 1;
  }

	if (IOs.jsonInput.containsKey("set_spread")) {
		StepMotor.EnableSpread((bool)IOs.jsonInput["set_spread"]);
		ValidKey = 1;
	}

  if (ValidKey == 0) {
    IOs.AddKeyValue_JSON("input_error", "unknown_command");
    IOs.Send_JSON();
  }

//	if (ValidKey == 0) {
//		IOs.Aknowledge_Json(false, "k");//valid key check failed
//	}
//	else {
//		IOs.Aknowledge_Json(true);
//	}
	IOs.jsonAvailable=0;
};

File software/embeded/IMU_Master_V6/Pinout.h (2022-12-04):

#pragma once

//PINS DECLARATION


//LEDS FOR FRONT DISPLAY
const int LEDB =6; 
const int LEDR =7;
const int LEDG =5;


const int Plus = 33;
const int Minus = 37;
const int SetupPin = 35;
const int Led = 3;

const int LockBNC = A9; // APPEAR AS LOCK ON MORJ FACE
const int SessionBNC = A10; // APPEAR AS SHUT.IN ON MORJ FACE  //// UNUSED
const int SutterOUTPUT_BNC = 31;//A8; // APPEAR AS STROB.IN ON MORJ FACE
const int SequenceBNC = 2; // APPEAR AS SHUT.OUT ON MORJ FACE

//DAQ GLOBAL VARS 

bool DAQ_real_mpos = 0;
bool DAQ_3ax = 0;
bool DAQ_9ax = 0;
bool DAQ_raw = 0;
bool DAQ_info = 1;

////WORK VARIABLES

bool IMU_connection_status = 0;

unsigned long SEQSTARTTIME = 0;
unsigned long SESSIONSTARTTIME = 0;
unsigned long SEQENDTIME = 0;

long LASTCOMMAND_MSG = 0;

bool SequenceStartFlag = 0;

bool Locked_state = 0;

long TRIALS = 0;

void setupPins() {
	pinMode(LEDG, OUTPUT);
	pinMode(LEDR, OUTPUT);
	pinMode(LEDB, OUTPUT);
	digitalWrite(LEDG , LOW);
	digitalWrite(LEDR , LOW);
	digitalWrite(LEDB , LOW);
      
	pinMode(Plus, INPUT_PULLUP);
	pinMode(SetupPin, INPUT_PULLUP);
	pinMode(Minus, INPUT_PULLUP);
	pinMode(Led, OUTPUT);

	//pinMode(LED_BUILTIN, OUTPUT);
	pinMode(LockBNC, INPUT_PULLUP);// POTENTIALLY DISCONNECTED INPUTS SET WITH PULLUPS TO AVOID NOISE JITTER ISSUES WHILE DISCONNECTED
	pinMode(SequenceBNC, INPUT_PULLUP);
	pinMode(SutterOUTPUT_BNC, OUTPUT);
	pinMode(SessionBNC, INPUT_PULLUP);
  
	digitalWrite(SutterOUTPUT_BNC , LOW);
}

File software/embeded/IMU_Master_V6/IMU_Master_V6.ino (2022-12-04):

/*
    Name:       IMU_Master_V6.ino
    Created:	20/10/2022 10:59:02
    Author:     XPS139370-1-DS\Timothe
*/
#include "JsonProtocol.hpp"
#include "IMU_Coupling.hpp"
#include "IMU_DMP.hpp"
#include "DigInputs.hpp"
#include "Acquisition.hpp"
#include "ShutterManager.hpp"
#include "LockManager.hpp"
#include "MotorControl.hpp"

//serial handlers
JsonProtocol ComPC = JsonProtocol(&Serial, __FILE__, __DATE__, __TIME__); // __FLAGS__ are Just some info to know which version of the code is compiled on the IMU -For traceability
JsonProtocol ComMotor = JsonProtocol(&Serial1);

//modules for the IMU and motor coupling
IMU_DMP IMU_sensor = IMU_DMP("imu");
IMU_Coupling Coupling_module = IMU_Coupling("coupling", &ComMotor);

//module that only forwards commands to motor
MotorForwarder forwarder_module = MotorForwarder("motor", &ComPC, &ComMotor);

//modules for the data acquisition
PollingInput Session_BNC = PollingInput("bnc_in_2", A10, INPUT_PULLUP);//Acq2_BNC is used for session trigger and is pin A10
RefractoryInterruptInput Sample_BNC = RefractoryInterruptInput("bnc_in_1",2,INPUT_PULLUP,RISING,1300000);//Acq1_BNC in used for precise sampling synchronization and is pin 2. We set the timing between two possible activations to 1.3 sec (in microseconds)
Acquisitions Acquisitions_manager = Acquisitions("records", &IMU_sensor, &Coupling_module);

//modules for the lock and shutter ios
LockInput Lock_BNC = LockInput("lock", A9, INPUT_PULLUP, &ComMotor);//lock in BNC is pin A9
ShutterManager Shutter_BNC = ShutterManager("shutter",31);//shutter out BNC is pin 31

//this tiny function must be defined before setup as we use it in setup. Il also uses global variables (Shutter_BNC etc) so we cannot define it in a class (or it will be too much complicated to make a modular thing for a situationnal need)
void interpret_motor_outputs(JsonObject& input_object){//all inputs from the jsonprotocol object that calls this will be forwarded through input_object
    //The jsonprotocol object that calls this function (defined in setup) is ComMotor. Hence, all inputs from motor are forwared to the PC outputs.
    if (input_object.containsKey("locked")) {
        if ((bool)input_object["locked"]) {
            Shutter_BNC.activate_shutter();
        }
        else {
            Shutter_BNC.deactivate_shutter();
        }
    }
}

void setup()
{
    Serial.begin(250000);
    Serial1.begin(115200);

    ComPC.set_aknowledging_mode(true);

    ComPC.outputDoc["MORJ_Controller"] = "started";
    ComPC.send_outputs();

    //DO STUFF AT RECEPTION OF MESSAGES :
    //MODULES THAT ARE RESPONSIBLE FOR THE MORJ OPERATION
    ComPC.add_listening_module(IMU_sensor);
    ComPC.add_listening_module(Coupling_module);
    ComPC.add_listening_module(Lock_BNC);
    ComPC.add_listening_module(Shutter_BNC);
    ComMotor.add_extenal_listener(&interpret_motor_outputs);// execute custom function on reception of motor outputs like shutter on locked.
    //MODULES THAT ARE RESPONSIBLe for DATA SYNCHRONIZATION AND ACQUISITION
    ComPC.add_listening_module(Acquisitions_manager);
    ComPC.add_listening_module(Sample_BNC);
    ComPC.add_listening_module(Session_BNC);

    //BIDIRECTIONNAL MOTOR ACCESS:
    //(MOTOR -> PC)
    ComMotor.set_copy_on_reception_document(&ComPC.outputDoc);// (MOTOR -> PC) 
    //(PC -> MOTOR)
    ComPC.add_listening_module(forwarder_module);// the module forwarder_module will allow you to write directly to the motor. (PC -> MOTOR)
    //(MORJ -> MOTOR  : COPY TO PC )
    //ComMotor.set_copy_on_emission_document(&ComPC.outputDoc);// usuefull only for debugging. Comment otherwise 
    
    //Set on wich output to send acquisition data and metadata
    Acquisitions_manager.set_output_document(&ComPC.outputDoc);

    delay(200);

    //SETTING UP THE IMU CONNEXION
    IMU_sensor.begin();
    IMU_sensor.connect();
    if (IMU_sensor.connected) {
        IMU_sensor.setup_DMP();
        if (IMU_sensor.dmp_setup) {
            ComPC.outputDoc["IMU_status"] = "connected";
        }
    }
    if (!IMU_sensor.connected || !IMU_sensor.dmp_setup) {
        ComPC.outputDoc["IMU_status"] = "connexion_failed";
    }
    //IMU_sensor.initialize_fake_data();//USEFULL ONLY FOR DEBUGGING. COMMENT OTHERWISE
}

void loop()
{
    ComPC.recieve_inputs();
    ComMotor.recieve_inputs();

//Data extraction

    //IMU_sensor.handle_connection_losses(ComPC.outputDoc); //check if it works by uncommenting this, seemed to do strange things. If you don't see disconnexions, i advise to better left this commented.
    IMU_sensor.get_data();
    //IMU_sensor.get_fake_data();//USEFULL ONLY FOR DEBUGGING. COMMENT OTHERWISE
    
//Coupling live data to the motor

    Coupling_module.update_coupling_orientation(IMU_sensor.quaternion_data.yaw());//updates yaw and turns for command calculation
    Coupling_module.update_motor();//sends command to motor if the movement threshold is passed, and if coupled

//Locking management (shutter management is done upwards, in the function "interpret_motor_outputs")

    Lock_BNC.poll();
    Lock_BNC.lock_update();

//Acquisition management

    Session_BNC.poll();
    if (Session_BNC.rising()) {
        Acquisitions_manager.start_session();
    }
    if (Session_BNC.falling()) {
        Acquisitions_manager.end_session(); 
    }

    if (Sample_BNC.is_activated()) {
       Acquisitions_manager.start_trial((Sample_BNC.get_activation_time()/1000)-1);//start new trial synchonized data, and give the start time of the trial, in milliseconds (hence /1000 because get_activation_time is in micros)
    }
    if (Acquisitions_manager.trial_duration_timer.elapsed()) {
        Acquisitions_manager.end_trial();
    }
    Acquisitions_manager.aggregate_due_data();// send data to pc on a regular basis. Deactivates automatically when we save data based on an external signal (500Hz BNC)

    ComMotor.send_outputs();
    ComPC.send_outputs();
}

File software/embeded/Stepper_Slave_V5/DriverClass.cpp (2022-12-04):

#include "DriverClass.h"
//#include <avr/io.h>
//#include <avr/interrupt.h>
//#include <ArduinoJson.h>
//#include <TMCStepper.h>

MORJStepperDriver::MORJStepperDriver(Stream& _TMC_UART, float r_sense, uint8_t address, int StepPin, int DirPin, int MS1Pin, int MS2Pin) : TMC2209Stepper(&_TMC_UART, r_sense, address), AccelStepper(AccelStepper::DRIVER, StepPin, DirPin)
{
	pinMode(StepPin, OUTPUT);
	pinMode(DirPin, OUTPUT);

	pinMode(MS1Pin, OUTPUT);
	pinMode(MS2Pin, OUTPUT);
	digitalWrite(MS1Pin, LOW);
	digitalWrite(MS2Pin, LOW);

	_address = address;
	//AccelStepper(AccelStepper::DRIVER, StepPin , DirPin);
	//TMC2209Stepper(&TMC_UART, r_sense, address);
}

void MORJStepperDriver::begin(int GearReductionRatio, int StepsPerRevolution, int microstepping, int EnablePin, Stream& DATAport) {

	_EnablePin = EnablePin;
	pinMode(_EnablePin, OUTPUT);
	digitalWrite(_EnablePin, LOW);
	_mot_enabled = true;

	TMC2209Stepper::begin();
	_curr_command = 0;

	TMC2209Stepper::microsteps(microstepping);

	_GearRed = GearReductionRatio;
	_StperRev = StepsPerRevolution;
	_microsteps = microstepping;

	//_DATAport = &DATAport;
	//_DATAport = DATAport;

	CalculateIncperRev();

	TMC2209Stepper::en_spreadCycle(true);
}

void MORJStepperDriver::SetLedMode(bool mode) {
	_led_active = mode;
	if (!_led_active) {
		digitalWrite(_Pin_LED, LOW);
		digitalWrite(LED_BUILTIN, LOW);
	}
	else {
		digitalWrite(_Pin_LED, HIGH);
		digitalWrite(LED_BUILTIN, HIGH);
	}
}

void MORJStepperDriver::SetMotorPrecision(int scale) {
	TMC2209Stepper::microsteps(scale);
	_microsteps = scale;
	CalculateIncperRev();
}

void MORJStepperDriver::SetMotorAcceleration(long accel) {
	_accel_rate = accel;
	AccelStepper::setAcceleration(_accel_rate);
}

void MORJStepperDriver::SetMotorCurrent(long current) {
	TMC2209Stepper::rms_current(current);
}

void MORJStepperDriver::SetMotorEnable(bool enb) {
	digitalWrite(_EnablePin, !enb);
	_mot_enabled = enb;
}

void MORJStepperDriver::SetZero() {
  AccelStepper::stop();
	//if (!AccelStepper::isRunning()) {
	AccelStepper::setCurrentPosition(0);
  _curr_command = 0;
		//AddKeyValue_JSON(F("zero"), F("M")); //SEND A MESSAGE TO SAY THAT THE MOTOR JUST SET IT'S ZERO
		//Send_JSON();
	//}
}

void MORJStepperDriver::StartRDO(long freq) { // delay in microseconds
	//AddKeyValue_JSON(F("RDO_delay"), (String)((long)(1000000 / freq))); //SEND A MESSAGE TO SAY THAT THE MOTOR IS UNLOCKED
	_RDOfreq = freq;
	_RDO_status = true;
}

void MORJStepperDriver::StopRDO() { // delay in microseconds
	_RDO_status = false;
}

void MORJStepperDriver::StopMotor() {
	AccelStepper::stop();
	_curr_command = AccelStepper::targetPosition();
}


//long id MORJStepperDriver::EstimateTurns(){
//  long pos = AccelStepper::currentPosition();
//  long turns = 0;
//  int supress;
//  
//  if (pos > 0) {
//    supress = -1;
//  }
//  else if (pos < 0) {
//    supress = 1;
//  }
//  else (){
//    supress = 0;
//  }
//
//  while (true) {
//    if (abs(pos) >= _IncperRev) {
//      pos = pos + (supress * _IncperRev);
//      turns = turns + 1;
//    }
//    else {
//      break;
//    }
//  }
//}

long MORJStepperDriver::Turns_Calc() {
  long temp_position = _curr_command;
  long temp_turns = 0;
  while (temp_position > _IncperRev || temp_position < 0){
    if (temp_position > _IncperRev){
      temp_turns = temp_turns + 1;
      temp_position = temp_position - _IncperRev;
    }
    else{
      temp_turns = temp_turns - 1;
      temp_position = temp_position + _IncperRev;
    }
  }
  return temp_turns;
};

void MORJStepperDriver::LockToNearestZero() {

	//long pos = _curr_command;
	long pos = AccelStepper::currentPosition();
	long turns = 0;
	int supress;

	_initlock = 1;
	_mot_locked = 1;

	if (pos > 0) {
		supress = -1;
	}
	else if (pos < 0) {
		supress = 1;
	}
	else {
		AccelStepper::moveTo(0);
		//AddKeyValue_JSON(F("lock"), F("F"));
		return; /// !! \\\ possible particular case, to handle later
	}
	//_DATAport->println(supress);

	while (true) {
		if (abs(pos) >= _IncperRev) {
			pos = pos + (supress * _IncperRev);
			turns = turns + 1;
		}
		else {
			break;
		}
	}
	//_DATAport->println(pos);

	if (abs(pos) > (long)(0.5 * _IncperRev)) {
		turns = turns + 1;
	}

	//AddKeyValue_JSON(F("lock"), F("S")); //SEND A MESSAGE TO SAY THAT THE MOTOR STARTS LOCKING
	//Send_JSON();
	//_DATAport->println(- supress * turns * _IncperRev);
	AccelStepper::moveTo(-supress * turns * _IncperRev);
}


void MORJStepperDriver::Unlock() {
	if (_mot_locked) {
		TMC2209Stepper::microsteps(_microsteps);
		TMC2209Stepper::en_spreadCycle(true);
		//AddKeyValue_JSON(F("lock"), F("U")); //SEND A MESSAGE TO SAY THAT THE MOTOR IS UNLOCKED
		//Send_JSON();
		_mot_locked = 0;
		AccelStepper::moveTo(_curr_command);
	}
}

void MORJStepperDriver::NewCommand(int16_t variation) {
	if (variation < _IncperRev * 3) {
		_curr_command = _curr_command + variation;
		if (_mot_locked == false) {
			//_DATAport->write(0x23);
			//_DATAport->write((uint8_t*)&variation, sizeof(variation));
			//_DATAport->println();
			AccelStepper::moveTo(_curr_command);
		}
	}
	AltLED();
}

bool MORJStepperDriver::AbsCommand(int32_t command) {
	if (abs(command - _curr_command < _IncperRev * 2)) {
		_curr_command = command;
		if (_mot_locked == false) {
			//_DATAport->write(0x23);
			//_DATAport->write((uint8_t*)&variation, sizeof(variation));
			//_DATAport->println();
			AccelStepper::moveTo(_curr_command);
      return 1;
		}
   return 0;
	}
 return 0;
	AltLED();
}

//void MORJStepperDriver::AddKeyValue_JSON(String key, String value) {
//    _buffer_stepDATA[key] = value;
//}

//void MORJStepperDriver::Send_JSON() {
//    serializeJson(_buffer_stepDATA, *_DATAport);
//    _DATAport->println();
//    _buffer_stepDATA.clear();
//}

void MORJStepperDriver::connectLED(int Pin_LED) {
	_Pin_LED = Pin_LED;
	pinMode(_Pin_LED, OUTPUT);
}

void MORJStepperDriver::EnableSpread(bool spread) {
	TMC2209Stepper::en_spreadCycle(spread);
}

bool MORJStepperDriver::EvaluateMovement() {
	if (_mot_locked) {
		if (_initlock) {
			if (AccelStepper::isRunning()) {
				AccelStepper::run();
			}
			else {
				TMC2209Stepper::en_spreadCycle(false);
				_initlock = 0;
        return true; //SEND A MESSAGE TO SAY THAT THE MOTOR FINISHED LOCKING
			}
		}
	}
	else {
		AccelStepper::run();
	}
  return false;
}

char* MORJStepperDriver::GetMotorScale(char* result) {
	dtostrf(_IncperRev, 12, 0, result);
	return result;
	//AddKeyValue_JSON(F("m_scale"), String(_IncperRev)); //SEND A MESSAGE TO SAY THAT THE MOTOR FINISHED LOCKING
	//Send_JSON();
}

void MORJStepperDriver::CalculateIncperRev() {
	_IncperRev = (int)_GearRed * _StperRev * _microsteps;
	//_DATAport->println(_IncperRev);
}

void MORJStepperDriver::WriteHEX_position(long data) { // 23(HEX) or # or 35(DEC): start byte , and then length of 4 bytes
	return;
	//_DATAport->write(0x23);
	//_DATAport->write((uint8_t*)&data, sizeof(data));
}
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

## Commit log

2022-12-04 documentation ongoing
    [Configuration.h]
2022-12-15 3D models
    [60mm_fan.SLDASM, BTR_M6.SLDPRT, BlocAdaptation.sldprt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]
